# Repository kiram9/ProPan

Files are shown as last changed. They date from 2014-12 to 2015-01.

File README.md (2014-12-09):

ProPan
======
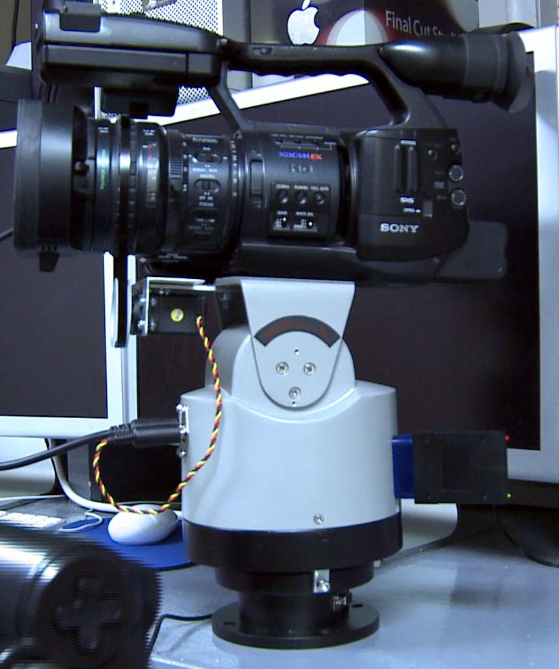
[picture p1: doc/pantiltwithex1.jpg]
ProPantilt Controller


Pan tilt control software and hardware documentation. 

Used to control a stepper based pan tilt head with a mounted sony EX-1 camera with zoom, pan, tilt, focus, and record controls. 

Compile src with arduino IDE, upload to ATMEGA 168 on board, and enjoy!

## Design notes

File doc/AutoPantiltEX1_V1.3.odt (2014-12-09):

# Auto Pan-Tilt V1.0 EX1

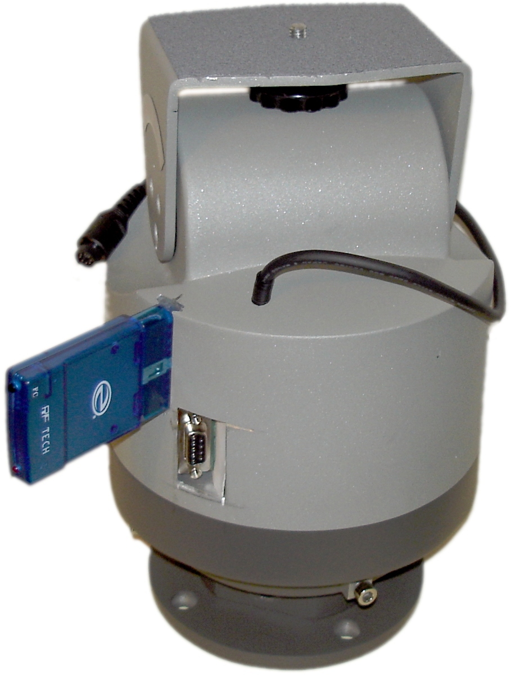
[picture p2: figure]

### Features:

- 24VDC operation
- Wireless range up to 100' (LOS)
- High accuracy
- Pan Angle: 350°
- Pan step size: 0.03°
- Tilt Angle: +/-50°
- Tilt step size: 0.01°
- Pan Speed: 0.04 to 6°/sec
- Tilt Speed: 0.02 to 3°/sec
- Ergonomic hand held controller
- Serial port control
- Open source Firmware
- Full Zoom, Focus, Record, shot review for the Sony EX-1 HD camcorder.
- Fully proportional controls
- Maximum load 6kg
- Weight 6.2kg

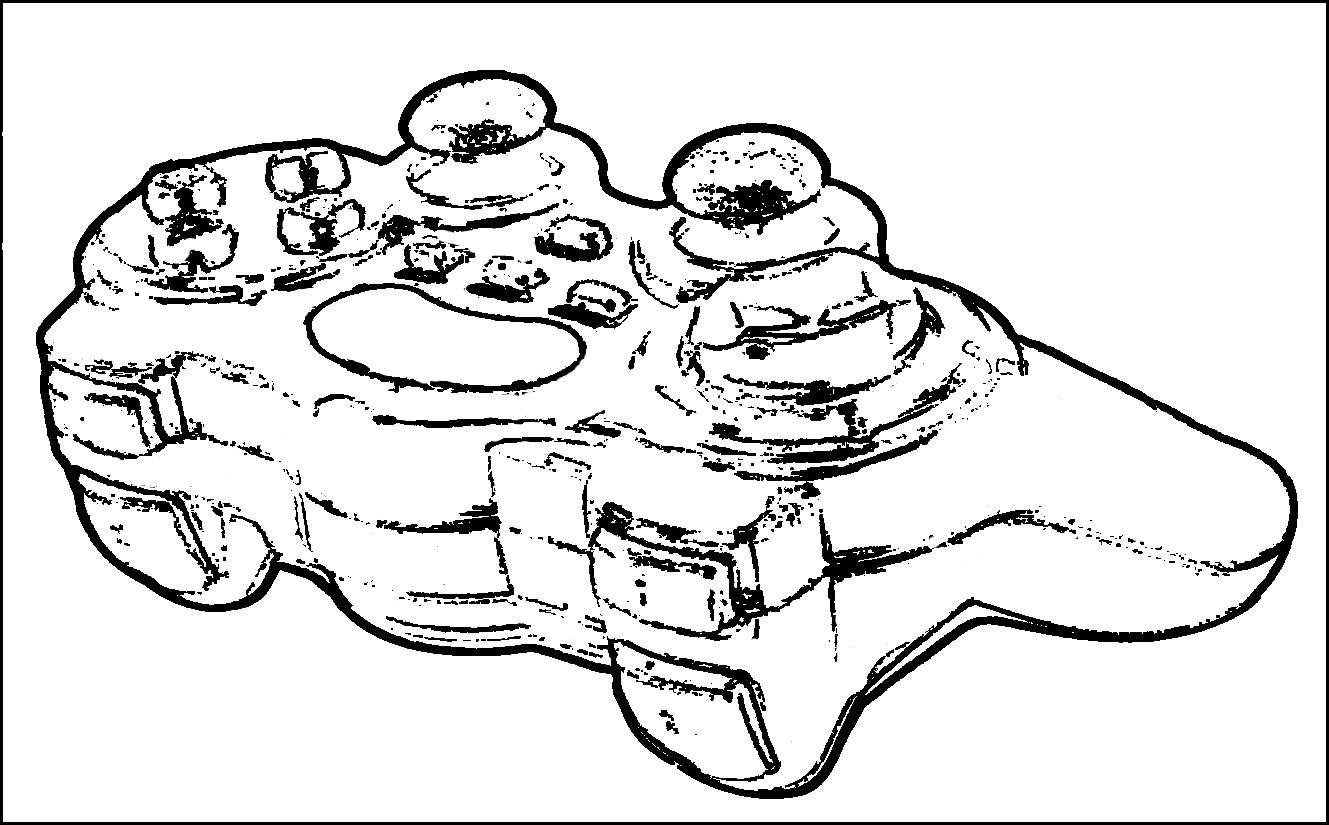
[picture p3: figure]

# Overview

The auto pan tilt with camera control wireless pan tilt head is designed for advanced motion control for the next generation of HD cameras. Incorporating 2.4GHZ hand held wireless controls, the common 24VDC power and a serial port allow this head to incorporate into almost any solution to provide high accuracy camera control at unparalleled cost. Designed for demanding environments where high precision and accuracy are a must. It also can also be used for remote sensor platform control, robotics, and range finding with its built in computer interface.

Custom configurations can be interfaced with almost any camera solution at additional cost. Other control solutions such as blue-tooth control, Zig bee based mesh networking interfaces, or integration with existing control solutions are also possible.

# Installation:

## Mounting:

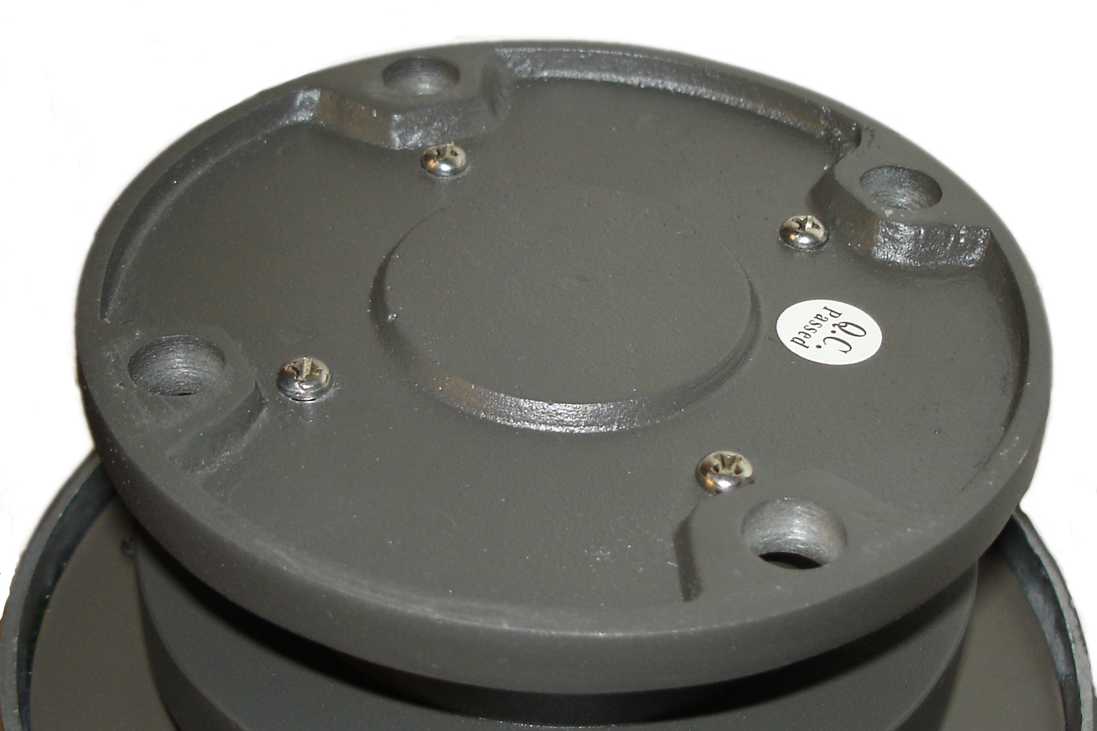
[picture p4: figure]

The Pan tilt head must be bolted using 4 bolts to a sturdy base. There is also a standard tripod mount in the middle of the base if a tripod mount is required. However for permanent operation 4 bolts to a sturdy base is preferred.

## Clearance:

Make sure that there is adequate clearance all around the camera head – whenever power is turned on the head must zero itself which means it will automatically rotate and tilt to the lower left maximum. Any equipment mounted on the head with attached cabling must have enough slack to allow this to occur otherwise damage to equipment or cabling may occur.

## Power:

The head needs 24VDC regulated power to function which is supplied through a standard center positive 2.5mm concentric barrel connector. This head should be used with the included power supply or a supply rated at least 1A at 24VDC. If using a wireless controller 4 AAA batteries are needed for the remote controller

# Controller

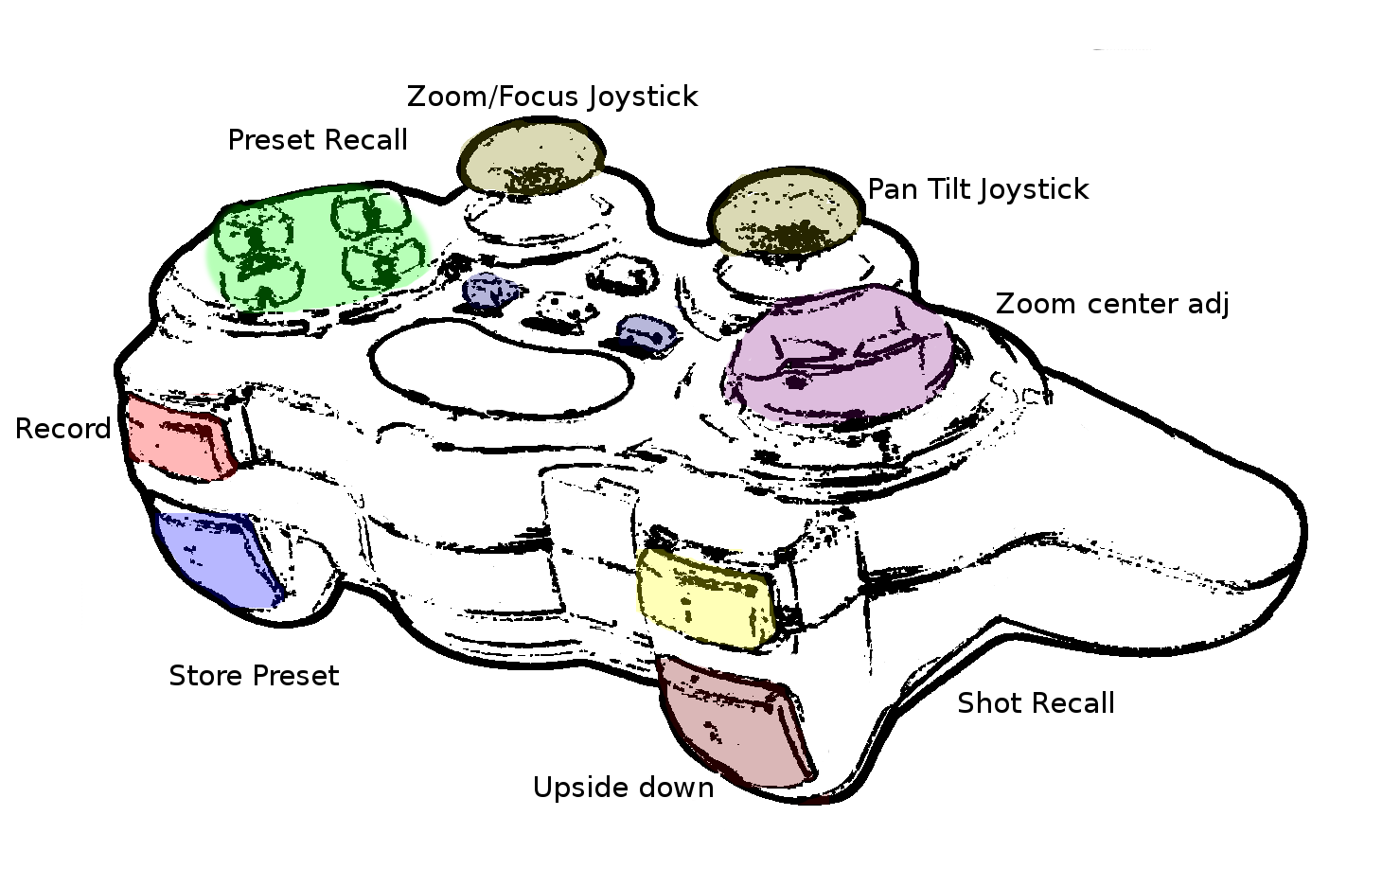
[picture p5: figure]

## Functions

### Pan and Tilt:

Using the pan tilt joystick fully proportional control of the head is assumed by the operator. A small movement of the joystick away from its center position will result in a slow pan or tilt. 8 levels of speed control are available for each direction of the pan and tilt. The Unit can be programmed to operate at very slow speeds. Using this method suitable for special filming requirements such as time-laps photography.

### Zoom and Focus

Moving the Zoom joystick forward and back will cause the zoom of the camera to zoom in and out proportionally. Currently the zoom cannot be recalled for specific presets.

### Focus (with optional accessory kit)

Moving the Zoom/Focus joystick left and right operates the focus control. This operates the special focus servo mounted under the camera allowing precision focus control.

### Record/Shot recall

The L1 and R1 buttons are used for record, and shot recall on the camera. Pressing the button will result in toggling the record/pause, and shot recall.

### Storing preset positions

To store a preset hold down the Store Preset button while selecting any one of the four preset recall buttons to overwrite the current position preset that is stored in that particular slot. These will only be stored until power loss unless the presets are stored to nonvolatile memory feature.

### Recalling preset positions

To recall a preset position press the corresponding preset recall position. If during the middle of the movement to a preset position the user requires to change the direction moving the joystick will cause the preset recall to abort and normal joystick control to resume.

## Calibration

### Setting Zoom zero point

At first use the controller will initialize to default values, this may be different from the camera's zero point. If you experience zoom creep ( a slow zooming in or out when the zoom joystick is centered) you can calibrate the zoom using the wireless controller. Hold the select button while pressing the zoom center adjust control up or down to adjust the center point. Continue this until the zoom no longer creeps in or out. This calibration will not be permanently stored through power loss until the store presets command is executed.

### Reversing the Pan tilt joystick

If reverse operation of the pan tilt joystick is required for mounting the camera backwards or upside down the joystick control can be reversed so the operator will not be confused. Hold down the select button and momentarily press the Upside down button to reverse control of the pan tilt joystick.

## Permanently storing presets, joystick settings and zoom zero point

To permanently store the zoom zero point, the pan tilt joystick reverse and all current position presets hold down the Select button and press Start. This saves all current settings into nonvolatile memory which will be saved through power loss.

# Remote Head

## Serial Port

## Power Connector

## Lens Connector

## Focus/Aux Connector

## Wireless Receiver Connector

# Physical Dimensions

# Serial Communication

## Connection information

The serial port should be connected using a straight through cable to a computer to allow serial communication. The serial port on the controller operates at 9600 baud with 8N1 format. Asserting the DTR line will cause the controller to reset.

## Boot up status information

When turning on the controller it will display via serial the firmware version as well initialization information regarding several subsystems inside the controller.

## Serial Command Structure

Serial commands are only enabled when the wireless joystick receiver is unplugged. Serial communication is entirely using human readable information. All commands will respond “OK” when received correctly.

Command | Space 0x20 | Variable 1 | Space (0X20) | Variable 2 | Linefeed 0x10
Move to pos | Space (0X20) | X position (0 to 11000) | Space (0X20) | Y position (0 to 9000) | Linefeed 0x10
M | Space (0X20) | 100 | Space (0X20) | 6438 | Linefeed 0x10
Set velocity | Space (0X20) | 1 or -1 are fastest | Linefeed 0x10
X | Space (0X20) | 1 | Linefeed 0x10
Y | Space (0X20) | -4 | Linefeed 0x10
Return current position | Returns coordinates in the form “X Y”
C | Linefeed 0x10
Run pan tilt head (enables pan – tilt unit)
G | Linefeed 0x10
Stop pan tilt head (Disables pan – tilt unit)
S | Linefeed 0x10
Toggle camera record
R | Linefeed 0x10
Set Zoom (relative speed, 0 to 255) values around 127 are approximately center
Z | Space (0X20) | 128 | Linefeed 0x10
Set Focus (relative focus, Number from 500 to 1500)
F | Space (0X20) | 900 | Linefeed 0x10

# Software Licensing

## Modifications

Modifications to the provided software or the use of other software with this unit which causes destruction or damage to the unit is will void all existing warranties. Any modifications to the unit (including software modifications are done entirely at the users risk, the manufacture provides no warranty, expressly or implied.

## GPL license

The firmware on this device is Licensed under GPL V3 by Kieran Levin. All source code is available for download at www.kieranlevin.com in compliance with the following license.

Copyright (C)2009 Kieran Levin

This program is free software: you can redistribute it and/or modify

it under the terms of the GNU General Public License as published by

the Free Software Foundation, either version 3 of the License, or

(at your option) any later version.

This program is distributed in the hope that it will be useful,

but WITHOUT ANY WARRANTY; without even the implied warranty of

MERCHANTABILITY or FITNESS FOR A PARTICULAR PURPOSE. See the

GNU General Public License for more details.

You should have received a copy of the GNU General Public License

along with this program. If not, see <http://www.gnu.org/licenses/>.

9 ©2009 Kieran Levin kieranlevin@kieranlevin.com

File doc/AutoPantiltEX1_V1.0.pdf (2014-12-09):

# Auto Pan-Tilt V1.0 EX1

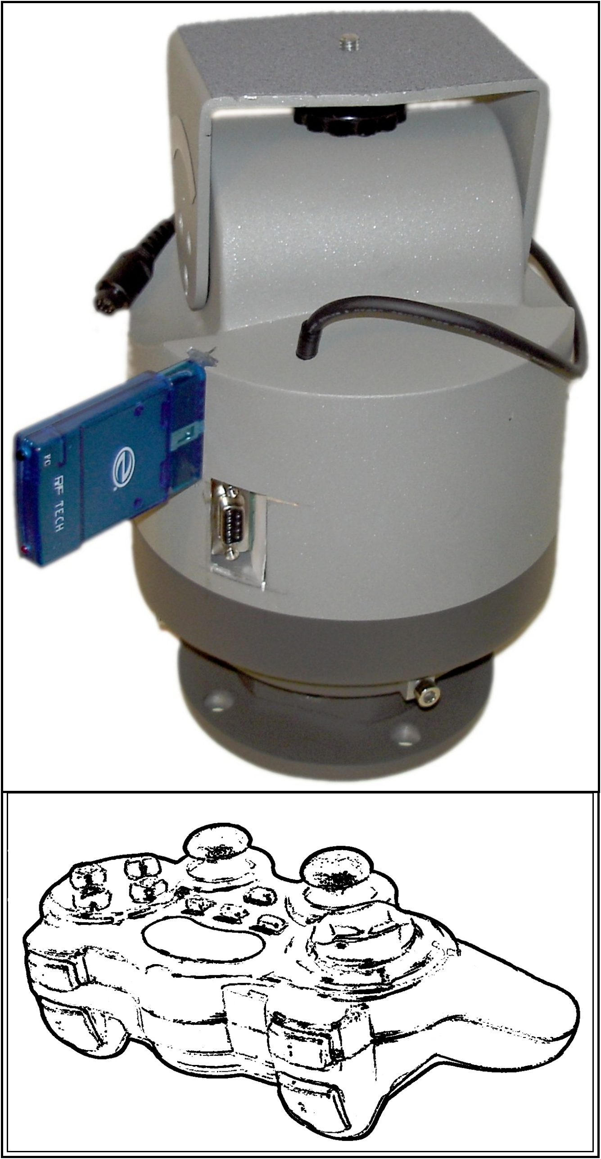
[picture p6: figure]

Features:
- 24VDC operation
- Wireless range up to 100'
- High accuracy
- Pan Angle: 350°
- Pan step size: 0.03°
- Tilt Angle: +/-50°
- Tilt step size: 0.01°
- Pan Speed: 0.04 to 6°/sec
- Tilt Speed: 0.02 to 3°/sec
- Ergonomic hand held controller
- Serial port control
- Open source Firmware
- Full Zoom, Record, shot review for the Sony EX-1 HD camcorder.
- Fully proportional controls
- Maximum load 6kg
- Weight 6.2kg
1 | ©2009 Kieran Levin kieranlevin@kieranlevin.com

## Table of Contents

## Overview

The auto pan tilt with camera control wireless pan tilt head is designed for advanced motion control for the next generation of HD cameras. Incorporating 2.4GHZ hand held wireless controls, the common 24VDC power and a serial port allow this head to incorporate into almost any solution to provide high accuracy camera control at unparalleled cost. Designed for demanding environments where high precision and accuracy are a must. It also can also be used for remote sensor platform control, robotics, and range finding with its built in computer interface.
Custom configurations can be interfaced with almost any camera solution at additional cost. Other control solutions such as blue-tooth control, Zig bee based mesh networking interfaces, or integration with existing control solutions is also possible.

## Installation:

Mounting:
The Pan tilt head must be bolted using 4 bolts to a sturdy base. This will not accept common bases such as camera tripods without a custom adapter.

Clearance:
Make sure that there is adequate clearance all around the camera head –

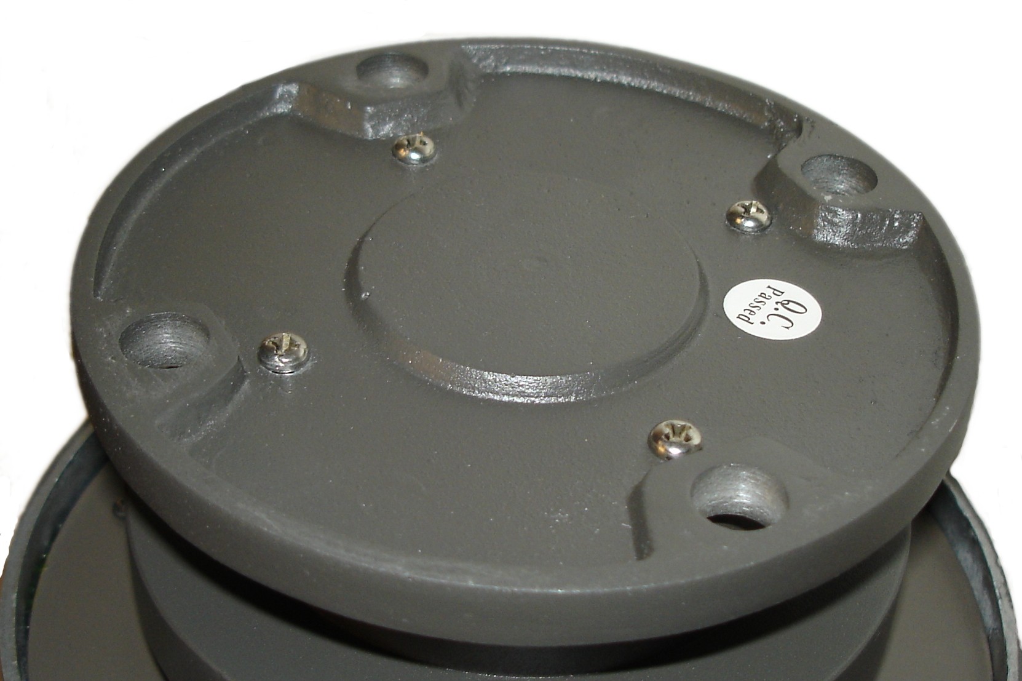
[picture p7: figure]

whenever power is turned on the head must zero itself which means it will automatically rotate and tilt to the lower left maximum. Any equipment mounted on the head with attached cabling must have enough slack to allow this to occur otherwise damage to equipment may occur.

Power:
The head needs 24VDC regulated power to function which is supplied through a standard center positive 2.5mm concentric barrel connector. This head should be used with the included power supply or a supply rated at least 1A at 24VDC. If using a wireless controller 4 AAA batteries are needed for the remote controller

## Controller

Functions

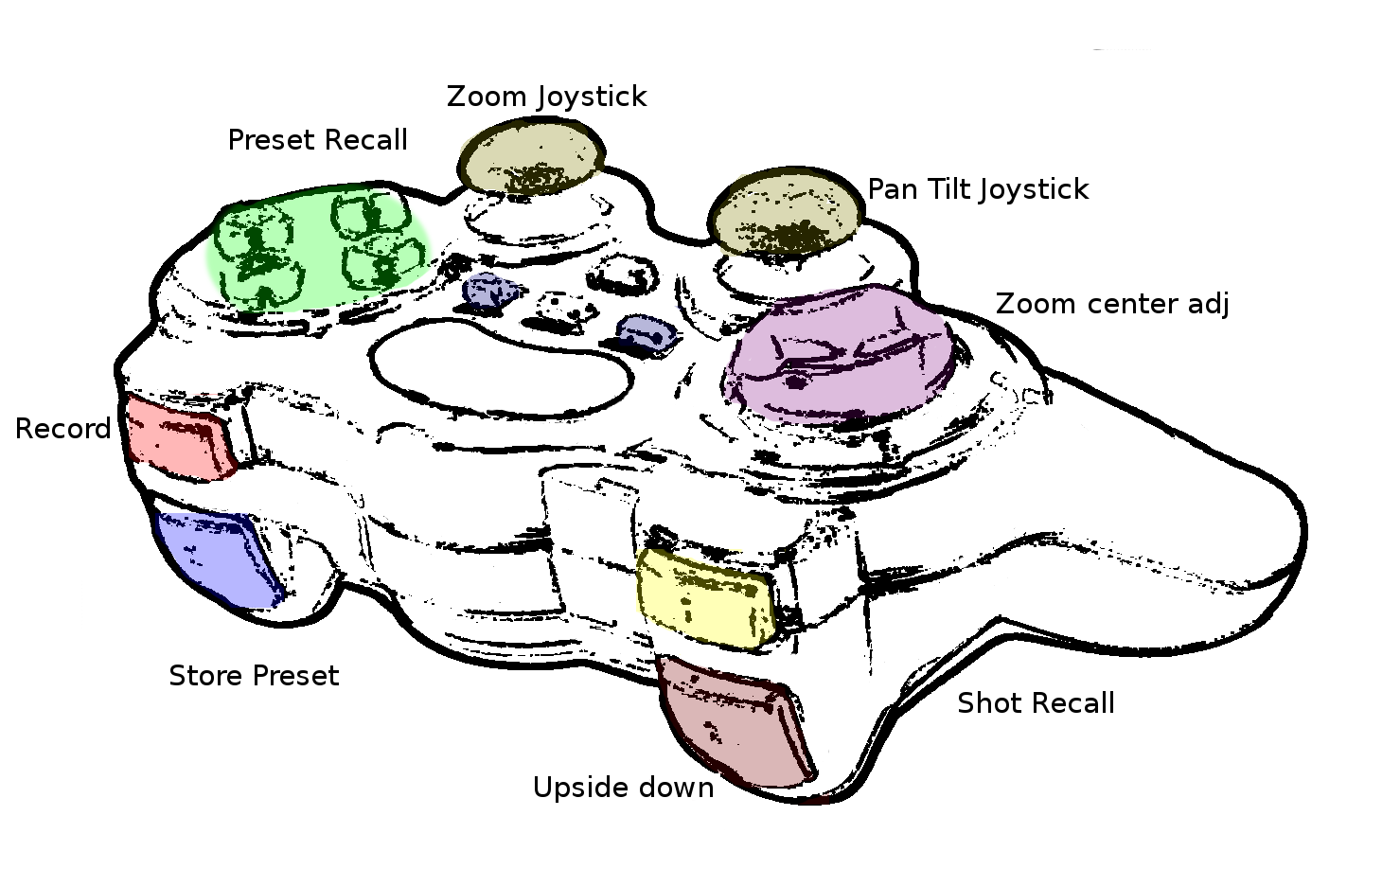
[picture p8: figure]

Pan and Tilt:
Using the pan tilt joystick fully proportional control of the head is assumed by the operator. A small movement of the joystick away from its center position will result in a slow pan or tilt. 8 levels of speed control are avaliable for each direction of the pan and tilt.

Zoom
Moving the Zoom joystick forward and back will cause the zoom of the camera to zoom in and out proportionally. Currently the zoom cannot be recalled for specific presets.

Record/Shot recall
The L1 and R1 buttons are used for record, and shot recall on the camera. Pressing the button will result in toggling the record/pause, and shot recall.

Storing preset positions
To store a preset hold down the Store Preset button while selecting any one of the four preset recall buttons to overwrite the current position preset that is stored in that particular slot. These will only be stored until power loss unless the presets are stored to nonvolatile memory feature.

Recalling preset positions
To recall a preset position press the corresponding preset recall position. If during the middle of the movement to a preset position the user requires to change the direction moving the joystick will cause the preset recall to abort and normal joystick control to resume.

## Calibration

Setting Zoom zero point
At first use the controller will initialize to default values, this may be different from the camera's zero point. If you experience zoom creep ( a slow zooming in or out when the zoom joystick is centered) you can calibrate the zoom using the wireless controller. Hold the select button while pressing the zoom center adjust control up or down to adjust the center point continue this until the zoom no longer creeps in or out. This calibration will not be permanently stored until the store presets command is executed.

Reversing the Pan tilt joystick
If reverse operation of the pan tilt joystick is required for mounting the camera backwards or upside down the joystick control can be reversed so the operator will not be confused. Hold down the select button and momentarily press the Upside down button to reverse control of the pan tilt joystick.

Permanently storing presets, joystick settings and zoom zero point
To permanently store the zoom zero point, the pan tilt joystick reverse and all current position presets hold down the Select button and press Start. The status LED on the controller will briefly go off to confirm that all current settings have been saved to nonvolatile memory.

## Serial Communication

Connection information
The serial port should be connected using a straight through cable to a computer to allow serial communication. The serial port on the controller operates at 9600 baud with 8N1 format. Asserting the DTR line will cause the controller to reset.

Boot up status information
When turning on the controller it will display via serial the firmware version as well initialization information regarding several subsystems inside the controller.

Serial Command Structure
Serial commands are only enabled when the wireless joystick receiver is unplugged. Serial communication is entirely using human readable information. All commands will respond “OK” when received correctly.
Command | Space 0x20 | Variable 1 | Space (0X20) | Variable 2 | Linefeed 0x10
Move to pos | Space (0X20) | X position (0 to 11000) | Space (0X20) | Y position (0 to 9000) | Linefeed 0x10
M | Space (0X20) | 100 | Space (0X20) | 6438 | Linefeed 0x10
Set velocity | Space (0X20) | 1 or -1 are fastest | Linefeed 0x10
X | Space (0X20) | 1 | Linefeed 0x10
Y | Space (0X20) | -4 | Linefeed 0x10
Return current position | Returns coordinates in the form “X Y”
C | Linefeed 0x10
Run pan tilt head (enables pan – tilt unit)
G

Linefeed
0x10
Stop pan tilt head (Disables pan – tilt unit) S

Linefeed
0x10
Toggle camera record
R

Linefeed
0x10
Set Zoom (relative speed, 0 to 255) values around 127 are approximately center Z

Space

(0X20) | 128 | Linefeed 0x10

## Software Licensing

Modifications
Modifications to the provided software or the use of other software with this unit which causes destruction or damage to the unit is will void all existing warranties. Any modifications to the unit (including software modifications are done entirely at the users risk, the manufacture provides no warranty, expressly or implied.

GPL license
The firmware on this device is Licensed under GPL V3 by Kieran Levin. All source code is available for download at www.kieranlevin.com in compliance with the following license.
Copyright (C)2009 Kieran Levin

This program is free software: you can redistribute it and/or modify
it under the terms of the GNU General Public License as published by the Free Software Foundation, either version 3 of the License, or
(at your option) any later version.

This program is distributed in the hope that it will be useful,
but WITHOUT ANY WARRANTY; without even the implied warranty of MERCHANTABILITY or FITNESS FOR A PARTICULAR PURPOSE. See the GNU General Public License for more details.

You should have received a copy of the GNU General Public License
along with this program. If not, see <http://www.gnu.org/licenses/>.

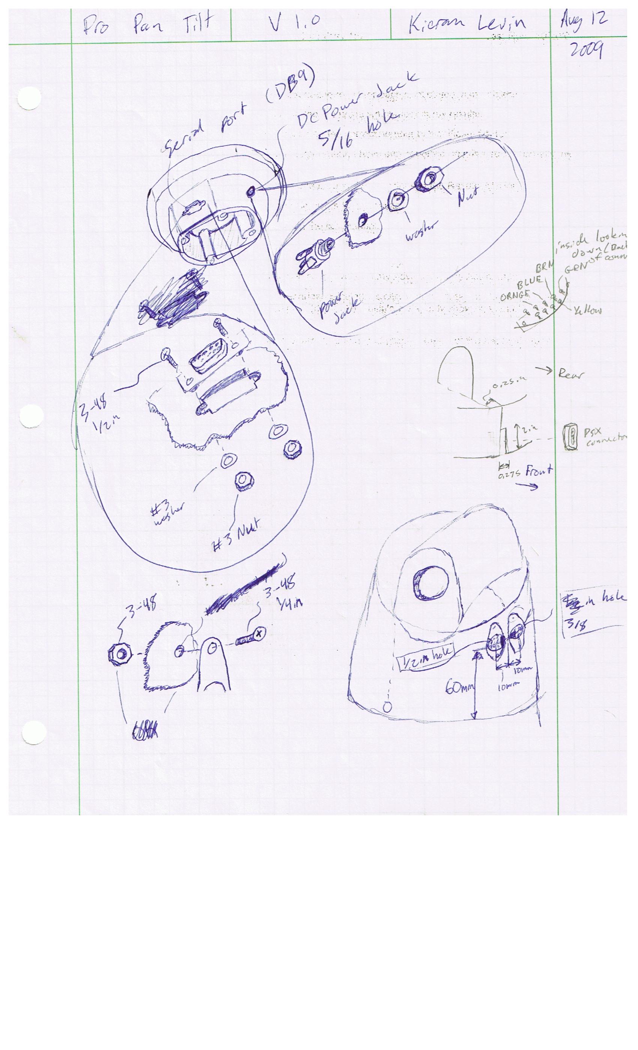
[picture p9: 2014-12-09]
doc/propantilt 001.jpg

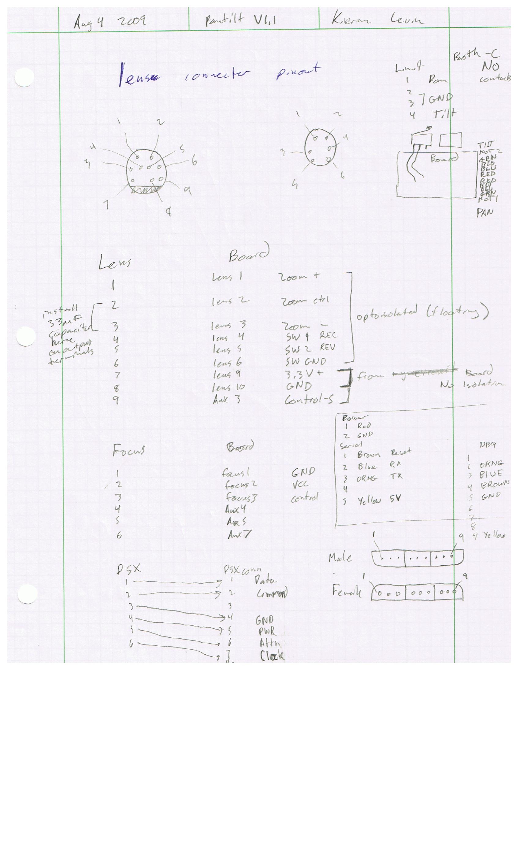
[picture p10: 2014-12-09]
doc/propantilt 002.jpg

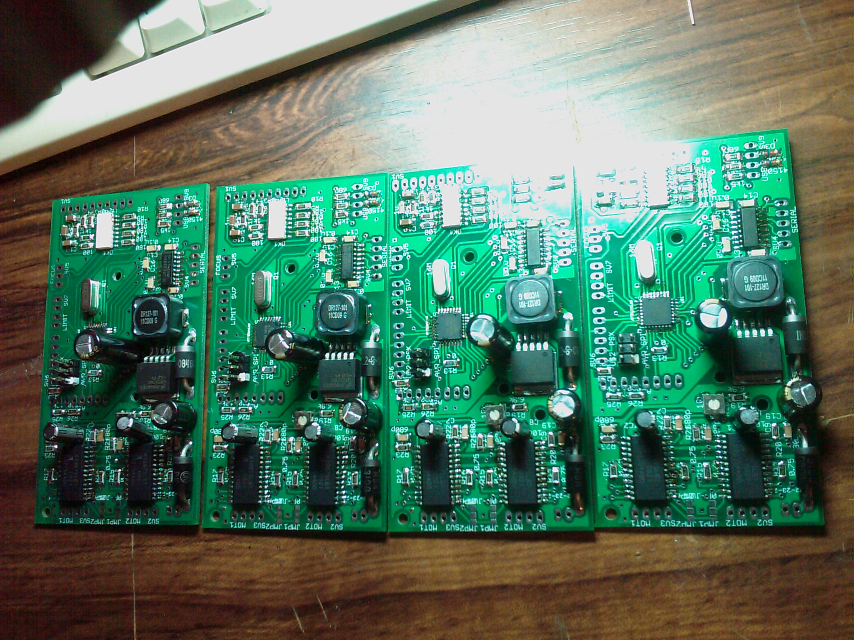
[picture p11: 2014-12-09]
doc/IMAG0068.jpg

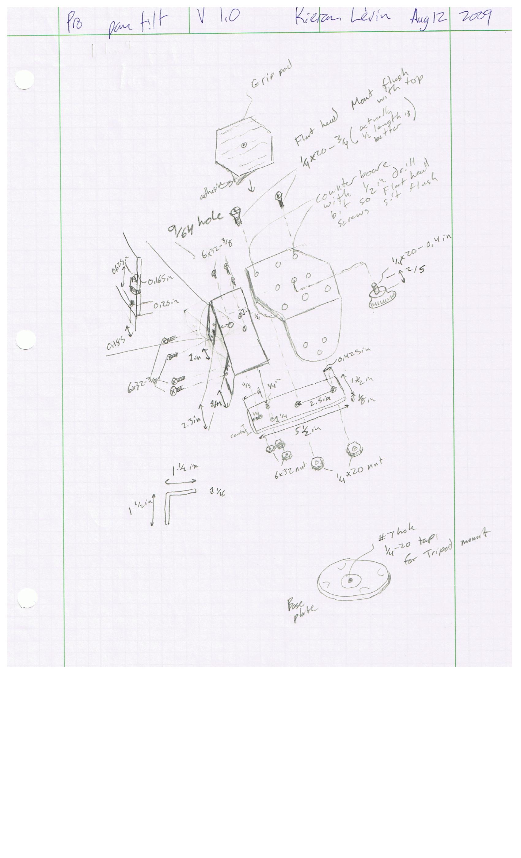
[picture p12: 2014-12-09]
doc/propantilt 003.jpg

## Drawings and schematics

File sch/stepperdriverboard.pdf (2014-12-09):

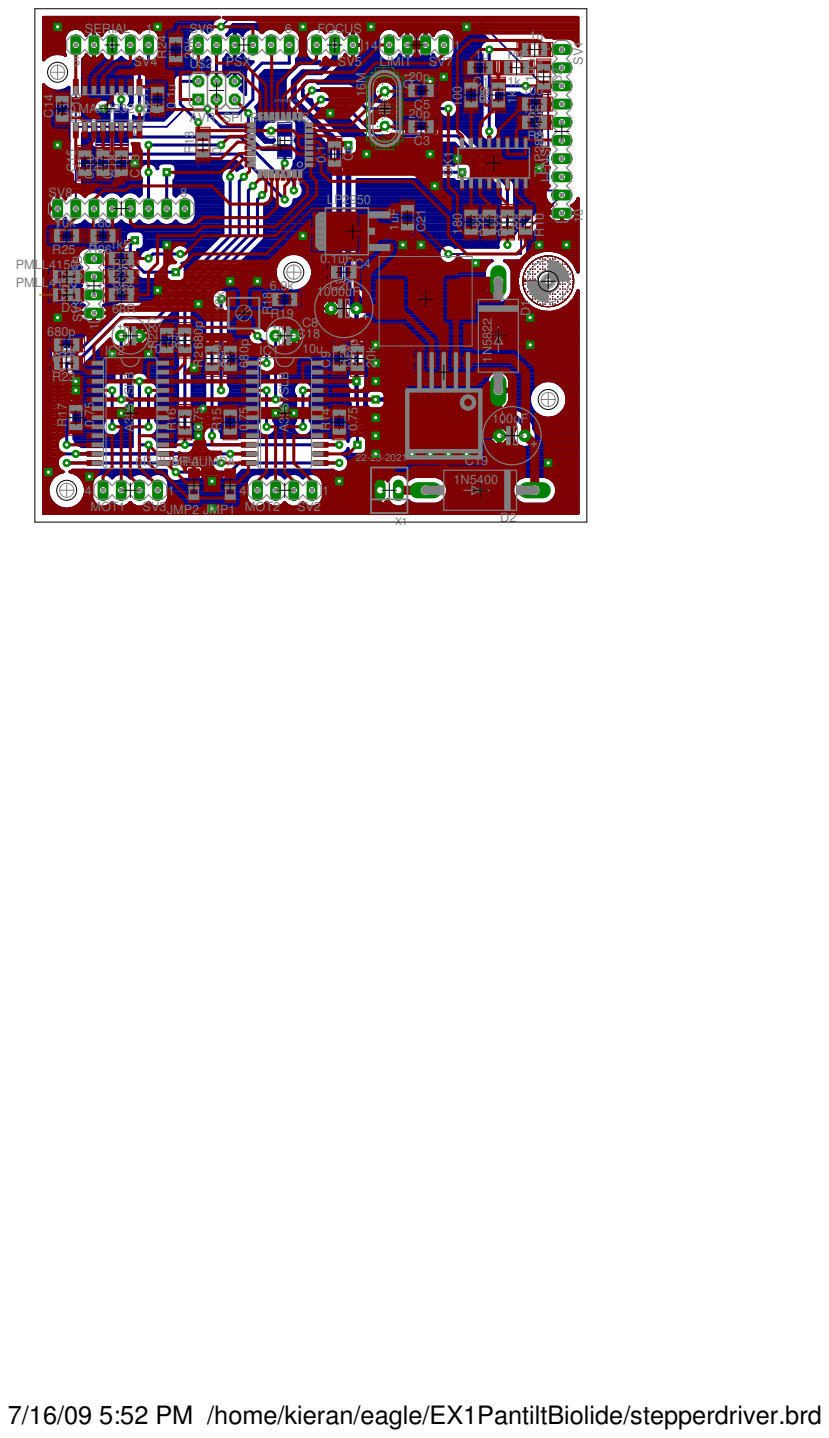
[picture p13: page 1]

7/16/09 5:52 PM /home/kieran/eagle/EX1PantiltBiolide/stepperdriver.brd

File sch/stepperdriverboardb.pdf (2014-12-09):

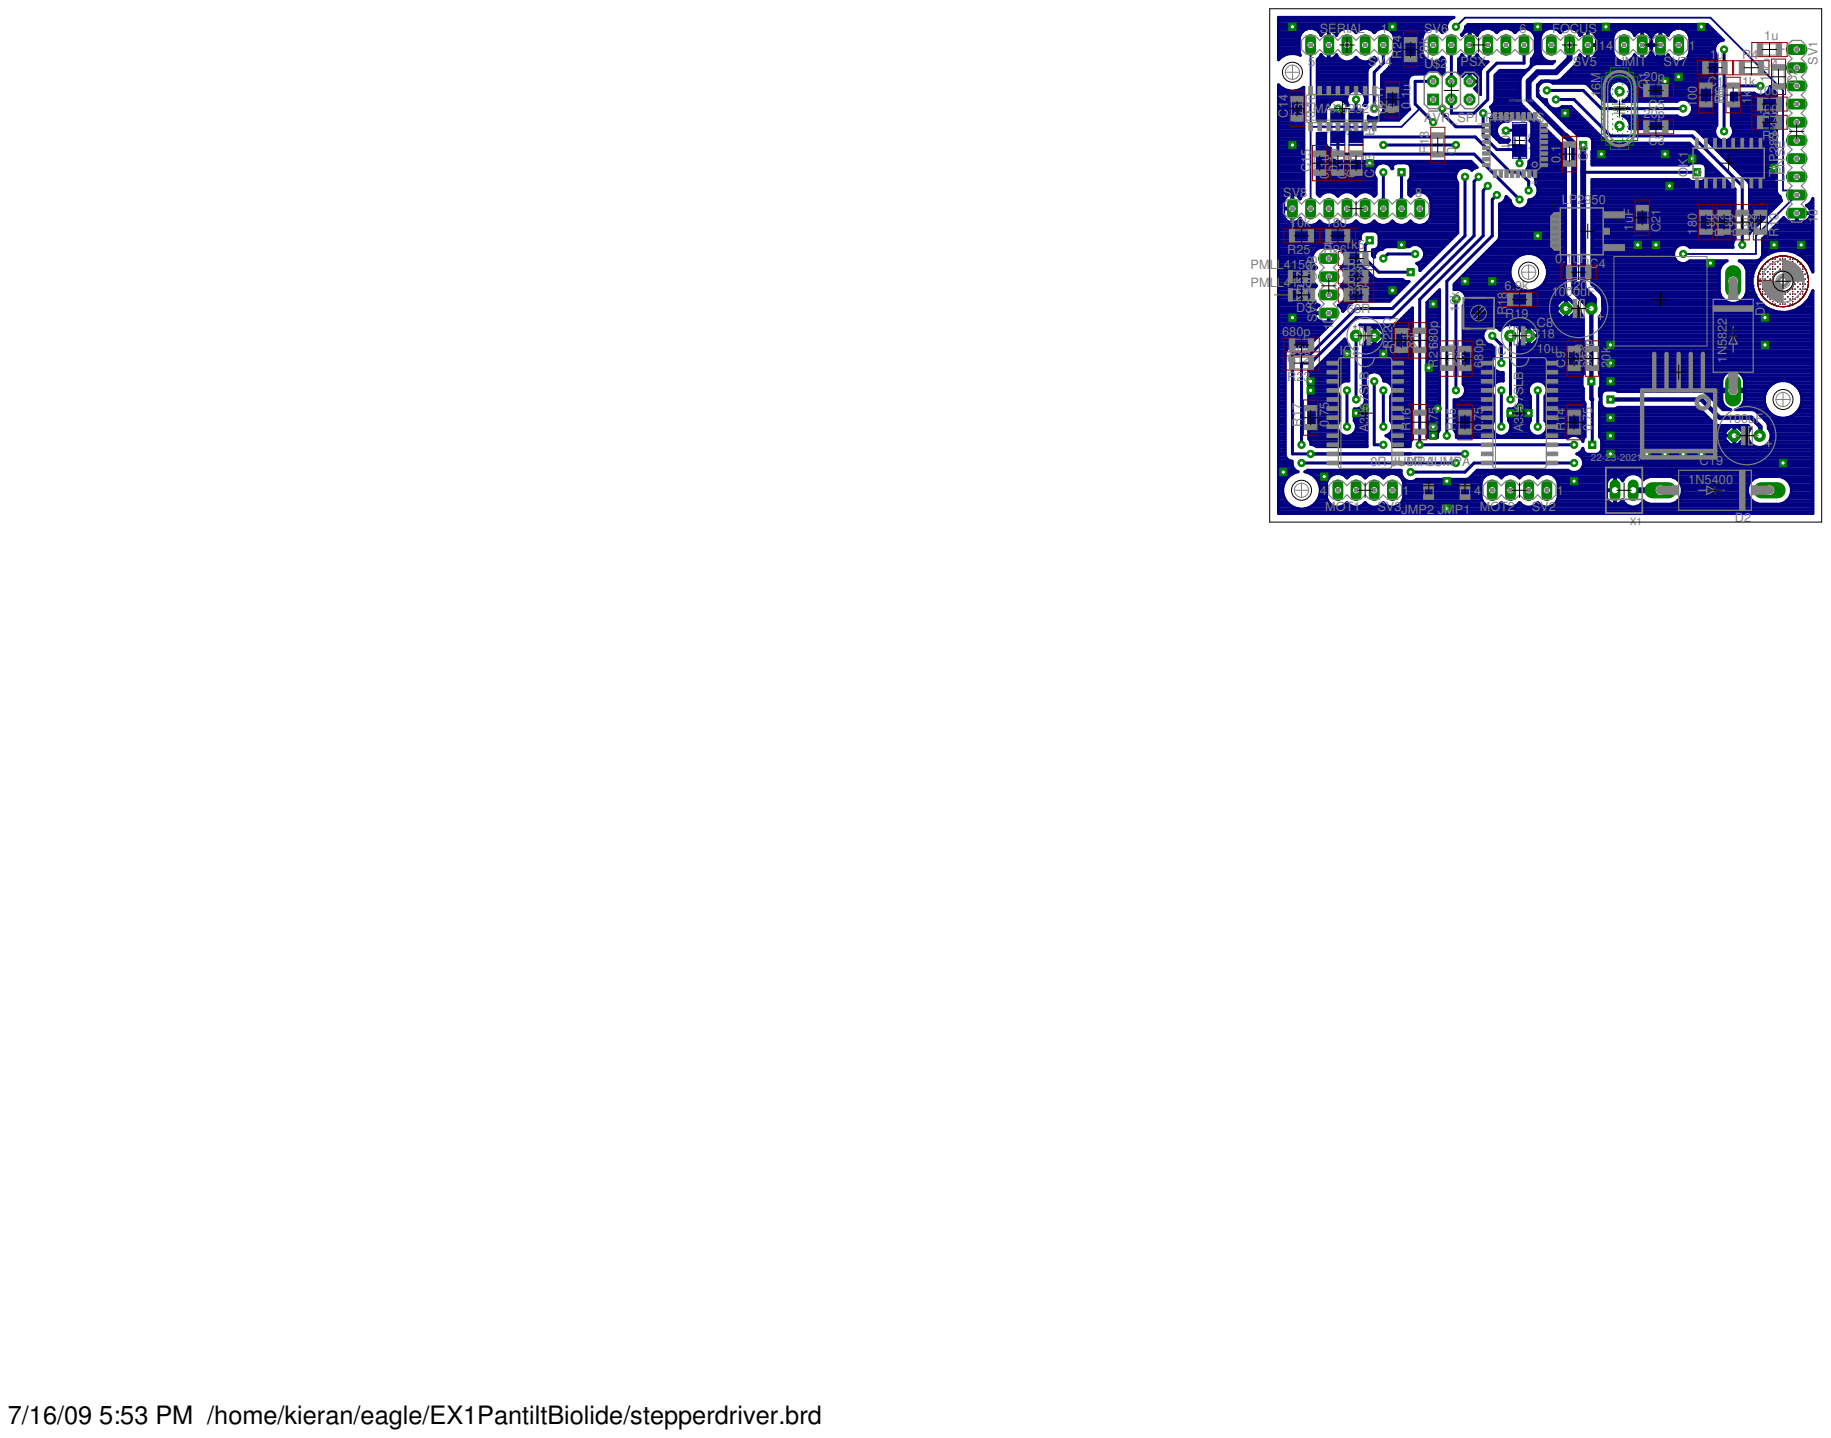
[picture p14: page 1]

0R-JUM0RP-AJUMPA | 22-23-2021

7/16/09 5:53 PM /home/kieran/eagle/EX1PantiltBiolide/stepperdriver.brd

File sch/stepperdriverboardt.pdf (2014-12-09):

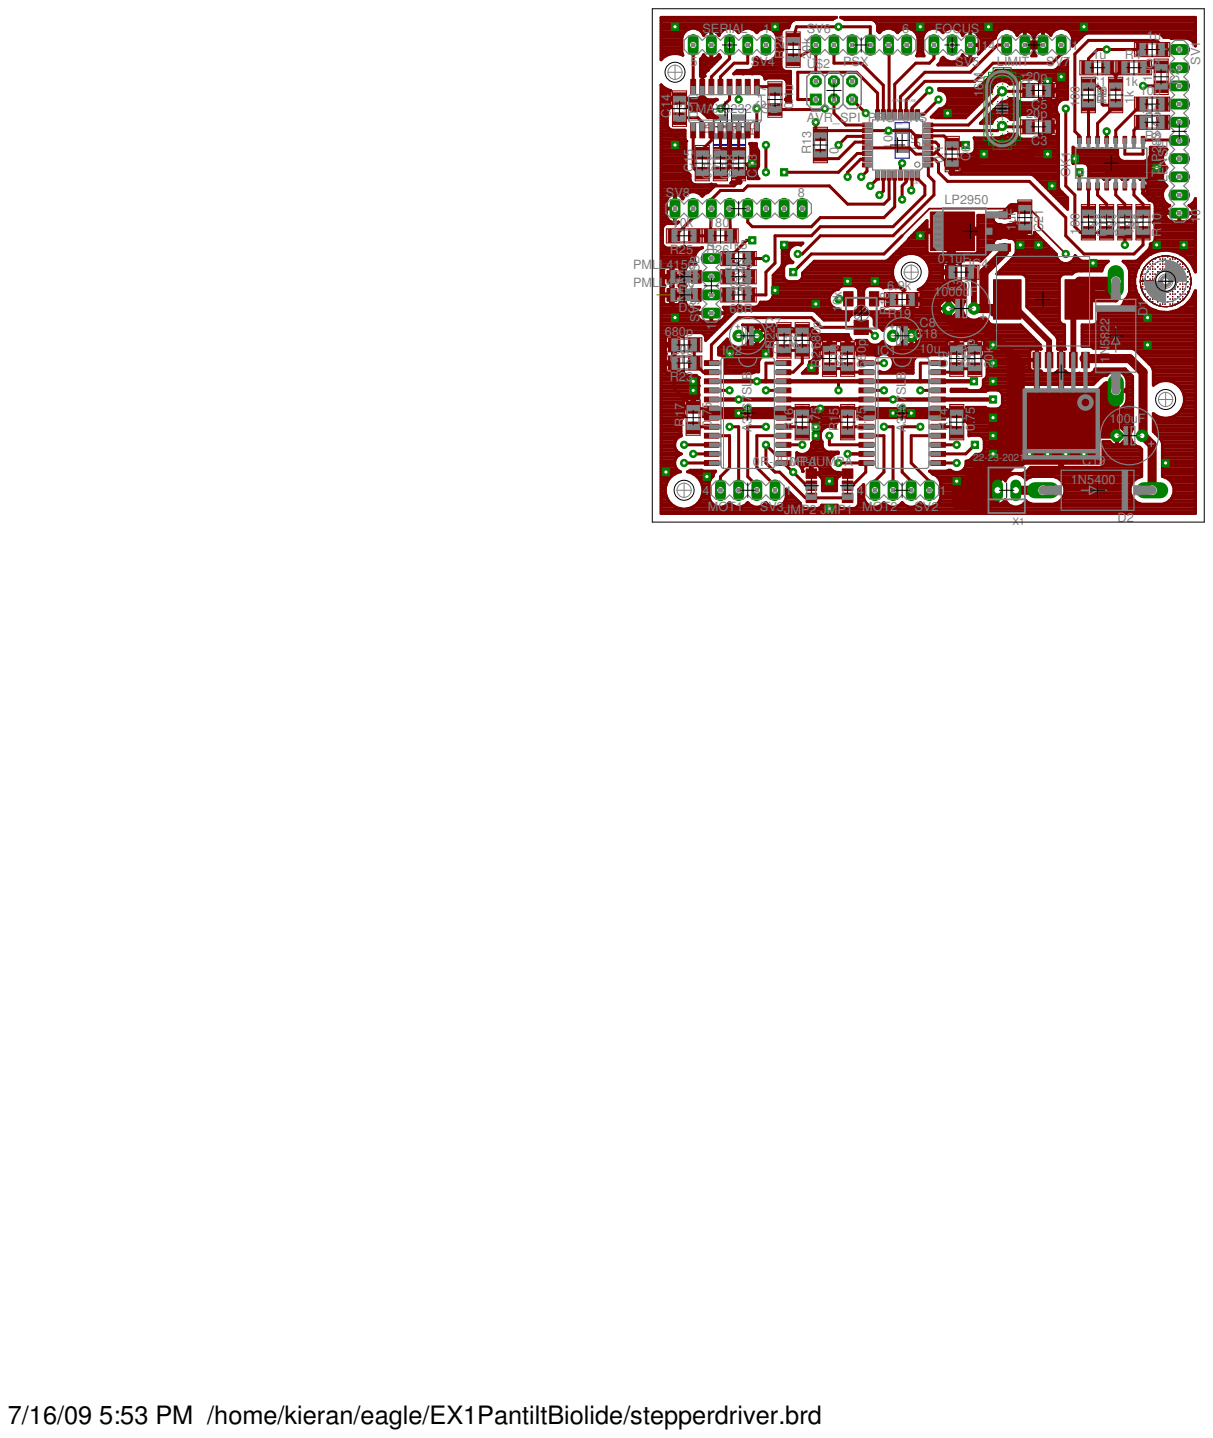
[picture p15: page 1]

SERIAL | FOCUS

7/16/09 5:53 PM /home/kieran/eagle/EX1PantiltBiolide/stepperdriver.brd

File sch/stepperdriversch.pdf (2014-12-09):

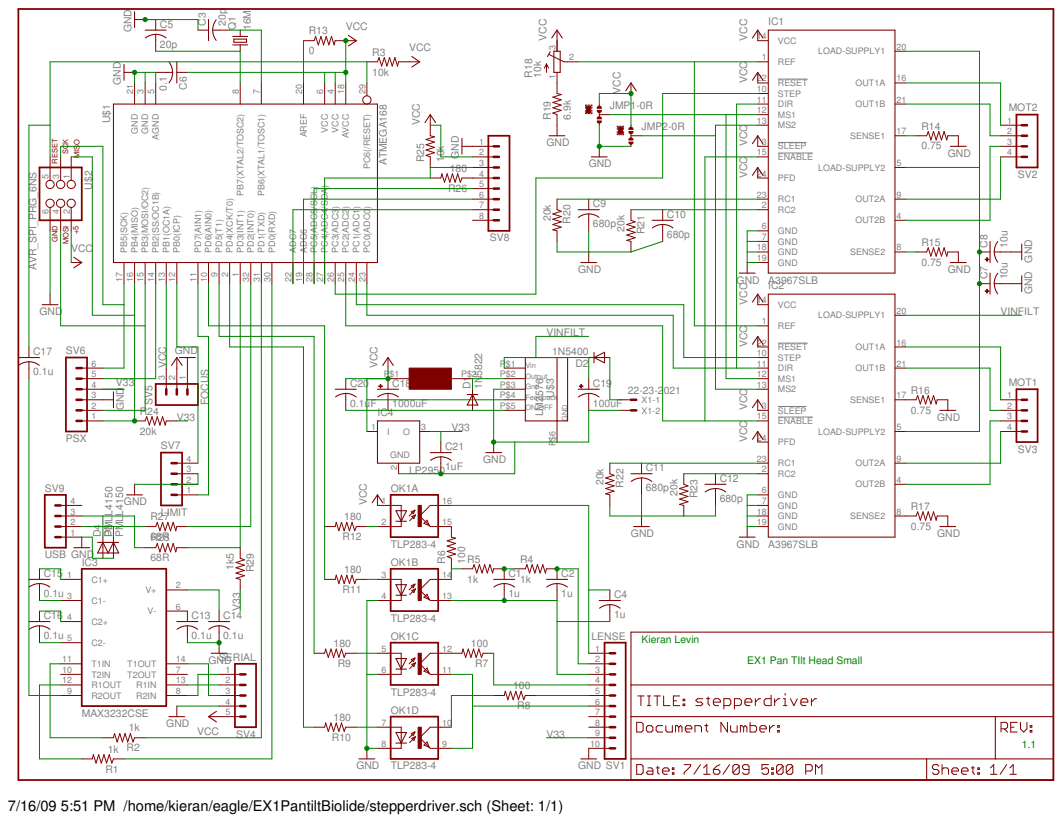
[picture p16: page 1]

VCC VCC VCC

MOSI RESET SCK MISO +5 GND

PB4(MISO) 16 PB3(MOSI/OC2) 15 PB2(SS/OC1B) 14 PB1(OC1A) 13 PB0(ICP) 12 PD7(AIN1) 11 PD6(AIN0) 10 PD5(T1) 9 PD4(XCK/T0) 2 PD3(INT1) 1 PD2(INT0) 32 PD1(TXD) 31 PD0(RXD) 30 ADC7

7/16/09 5:51 PM /home/kieran/eagle/EX1PantiltBiolide/stepperdriver.sch (Sheet: 1/1)

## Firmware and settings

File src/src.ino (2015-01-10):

/*  Pan tilt controller library (EX1Pantilt.pde)
	Written by: Kieran Levin Dec 13th, 2011
	
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
    You should have received a copy of the GNU General Public License
    along with this program.  If not, see <http://www.gnu.org/licenses/>.
*/
//TODO FIX VELOCITY RAMPING FUNCTIONS IN ATMSTEPPER.CPP 
#define VERSION  "Pan Tilt V1.3C C 2014 Kieran Levin"
#include <Spi.h>
#include <Psx_analog.h>                                          // Includes the Psx Library 

#include <ATmStepper.h>

#include <EEPROM.h>

#include <Messenger.h>

//#include <Servo.h>
#include <ServoTimeTimer1.h>
////////////////////////////////////
//Motor Definition 
//was 5
 #define StepFreqMax 5
//#define StepFreqMax 3

#define PinTiltLim 8
#define PinPanLim 7

#define PinMotorEnable 16
#define PinMotorDir 14
#define PinMotorPanStep 15
#define PinMotorTiltStep 17


/////////////////////////////////////
//Messenger definition 
Messenger message = Messenger(); 

////////////////////////////////////
//Servo definition 
#define PinServo 9
//Servo servFocus;
ServoTimeTimer1 servFocus;
uint16_t serv_cal;
///////////////////////////////////
//Controller pins definition 
#define PinData 12
#define PinCmnd 11
#define PinAtt 10
#define PinClock 13

Psx Psx;                                                  // Initializes the playstation library 
////////////////////////////////////
//Camera pins definition 
#define PinZoom  6 
#define PinRec 5
#define PinMode 4

#define CENTER  0x80
//nomalized x^3 curve to allow finer resolution control for lower values....
/*
unsigned char modifier[128] = 
{
0,0,0,0,0,0,0,0,0,0,0,0,0,0,0,0,0,0,0,0,0,1,1,1,1,1,2,2,2,3,3,3,4,4,4,5,5,6,
6,7,7,8,9,9,10,11,12,12,13,14,15,16,17,18,19,20,21,23,24,25,26,28,29,31,32,34,
35,37,39,40,42,44,46,48,50,52,54,56,59,61,63,66,68,71,73,76,79,81,84,87,90,93,
96,100,103,106,110,113,117,120,124,128,132,136,140,144,148,152,156,161,165,170,
174,179,184,189,194,199,204,209,215,220,226,231,237,243,249,255};
*/
//offset value for the zoom centering algorithm 
int offset;
//general forloop counter 
int i;

char pressed; 
char mdebug; 

// bool to keep track if the ptz controls are flipped 
char flipped; 
// hold the preset positions 
unsigned int presets[4][2]; 
#define EEPROMVALID 0
#define EEPROMVALIDVAL 0xB0
#define EEPROMCENTER 1
#define EEPROMFLIP  2
#define EEPROMSERCAL 4
#define EEPROMMEMSTART 6
// converts the raw psx output (0 to 255) to my velocity commands 1 being the fastest
int psxtovelocity(byte raw)
{
   if (raw > 230)   return (1);
   if (raw > 204)   return (2);
   if (raw > 194)   return (3);
   if (raw > 184)   return (4);
   if (raw > 174)   return (5);
   if (raw > 164)   return (6);
   if (raw > 154)   return (7);     
   if (raw > 144)   return (8);
   if (raw > 112)   return (0);
   if (raw > 102)   return (-8);     
   if (raw > 92)    return (-7);
   if (raw > 82)    return (-6);
   if (raw > 72)    return (-5);
   if (raw > 62)    return (-4);
   if (raw > 52)    return (-3);
   if (raw > 25)    return (-2);

                    return (-1);   
     
}
// handles the zoom and zoom center offset 
byte zoommodifier(byte raw)
{
  int temp;

  temp = (offset + int(raw));   // reverse the direction 
  //bounds check.... 
  if(temp < 0) temp = 0; 
  if (temp > 255) temp = 255; 
 return byte(temp);   
}
// save all NVRAM data 
void savePresets()
{  
  noInterrupts();
                  EEPROM.write(EEPROMCENTER,byte(offset));
                  EEPROM.write(EEPROMFLIP,flipped); 
                  EEPROM.write(EEPROMSERCAL, serv_cal & 0x00FF);
                  EEPROM.write(EEPROMSERCAL+1, serv_cal >> 8);
                  for(i = 0; i < 4; i++)
                  {
                     EEPROM.write(EEPROMMEMSTART + 0 + (i << 2),byte(presets[i][0] & 0xFF));
                     EEPROM.write(EEPROMMEMSTART + 1 + (i << 2),byte(presets[i][0] >> 8));
                     EEPROM.write(EEPROMMEMSTART + 2 + (i << 2),byte(presets[i][1] & 0xFF));
                     EEPROM.write(EEPROMMEMSTART + 3 + (i << 2),byte(presets[i][1] >> 8));

                  }  
  interrupts();
}
//////////////////////////////////////////////////
// Updates the focus servo 
//#define POSMAX 3000
//#define POSMIN  1750
#define POSMIN  865 //not normal but for one head yes
//#define POSBACK  15
//uint16_t servPosition; 

//byte servPosFlags; 
//byte servPosCounter;
void updateFocus(byte raw)
{
  if ((raw > 148) || (raw < 108))
  servFocus.write(serv_cal + (raw >> 2)); 
  else 
  servFocus.write(serv_cal + 0x20); 
}

void printState(){
  
  Serial.print("\n");                                            // the button data
  Serial.print(Psx.Controller_mode, HEX);     // prints value as string in hexadecimal (base 16) 
  Serial.print(','); 
  Serial.print(Psx.digital_buttons, HEX);     // prints value as string in hexadecimal (base 16)  
  Serial.print(','); 
  Serial.print(Psx.Right_x, HEX);     // prints value as string in hexadecimal (base 16)    
  Serial.print(Psx.Right_y, HEX);     // prints value as string in hexadecimal (base 16)    
  Serial.print(Psx.Left_x, HEX);     // prints value as string in hexadecimal (base 16)    
  Serial.print(Psx.Left_y, HEX);     // prints value as string in hexadecimal (base 16)      
  Serial.print(','); 
  Serial.print(psxtovelocity(Psx.Left_x), DEC);
  Serial.print(',');

  Serial.print(ATmStepper::getpos1x(), DEC);
  Serial.print(','); 
  Serial.print(ATmStepper::getpos1y(), DEC);
    Serial.print(','); 
  Serial.print(serv_cal, DEC);
  
}

// prints help on the serial interface  (does not have enough program mem window to work...)
//void serialHelp()
//{
//      Serial.println(VERSION);
//      Serial.println("Help: ");   
//      Serial.println("Command Syntax = Char Value ... Value Value (Carrage return)");  
//      Serial.println("Move to position   : 'M 100 100'  ");  
//      Serial.println("Set X velocity     : 'X 1' or 'X -1'");  
//      Serial.println("Set Y velocity     : 'Y 1' or 'Y -1'");  
//      Serial.println("Return Coordinates : 'C' Returns X Y ");  
//      Serial.println("Run Pan tilt head  : 'G'");    
//      Serial.println("Stop Pan tilt head : 'S'");     
//      Serial.println("Camera Record      : 'R'");   
//      Serial.println("Zoom               : 'R Zval(0 to 255)'");
//      Serial.println("Help (this screen) : 'h or H'");         
//}
// handles all serial messages when they are ready 
void messageReady() 
{
  int temp = 0; 
  switch (message.readChar())
  {
    case 'M': //move to position
      if(message.available()) 
      ATmStepper::setpos(message.readInt(), message.readInt()); 
      break;
    case 'X': // set X velocity 
      if(message.available()) 
      ATmStepper::setvelocity1x(message.readInt());
      break; 
    case 'Y': // set Y velocity 
      if(message.available()) 
      ATmStepper::setvelocity1y(message.readInt());
      break;   
    case 'C': // get Coordinates (returns in form X Y)  
        Serial.print(ATmStepper::getpos1x(), DEC);
        Serial.print(' '); 
        Serial.print(ATmStepper::getpos1y(), DEC);
        Serial.println("  "); 
      break; 
    case 'G': // Run head 
      ATmStepper::run(); 
      break; 
    case 'S': // Stop head 
      ATmStepper::stop(); 
      break; 
    case 'R': // trigger record 
      digitalWrite(PinRec, HIGH);
      delay(10);
      digitalWrite(PinRec, LOW);
      break; 
    case 'Z': // operate zoom 
      analogWrite(PinZoom, byte(message.readInt() + offset));
      break; 
    case 'F': //operate focus 
      servFocus.write(message.readInt()); 
      break; 
    case 'h': 
    case 'H':// show help 
      Serial.println("Help: www.kieranlevin.com"); 
      break;     
    case 'u': //remote update frame
    case 'U':
  
      
      // output analog values to correct pins 
      updateFocus(message.readInt()); 
      
      temp = message.readInt(); //zoom control
      if (temp > 148 || temp < 108){
	    analogWrite(PinZoom, zoommodifier(255-temp));
      }
      else {
        analogWrite(PinZoom, zoommodifier(0x80));
      }
      
      ATmStepper::setvelocity1x(-psxtovelocity(message.readInt()));
      ATmStepper::setvelocity1y(psxtovelocity(message.readInt()));
      
      temp = message.readInt(); //button states...
      if ( (temp & 0x01) == 0x01 )
        digitalWrite(PinRec, HIGH);
      else 
        digitalWrite(PinRec, LOW);
        
      if ( (temp & 0xc) == 0x0c){
        Serial.println("Saving settings"); 
        savePresets();
        delay(1000);
      }else if ( (temp & 0xc) == 0x08){
        offset++;
        delay(250);
      }else if ( (temp & 0xc) == 0x04){
        offset--;
        delay(250);
      }
      //Serial.println("Got remote update"); 
      break; 
    case 'd':
    case 'D':
      mdebug = mdebug^1;
      break; 
      
    default: 
      Serial.println("Invalid"); 
      break; 
  }
      
       // Loop through all the available elements of the message
       while ( message.available() ) 
       {
	  // There must be some garbage at the end of the message
          message.readInt();
          Serial.println("Garbage in message Detected"); 
       }
       //Serial.println("OK"); 
}




// initialize the controller head 
void setup()
{
  //delay(10);
  Serial.begin(4800); 
  Serial.println(VERSION);
  Serial.println("Please wait..."); 
  ///////////////////////////////////////////
  Serial.println("Initializing..."); 
  Serial.println("\tHead...");
  delay(100);
  ATmStepper::ATmStepperInit(StepFreqMax,PinMotorPanStep,PinMotorTiltStep,PinMotorDir,PinMotorEnable,PinPanLim,PinTiltLim); 
  Serial.println("\tCentering Head...");
  //TmStepper::setpos(7000,5000);
  ATmStepper::setpos(70,50);
  delay(300);
  /////////////////////////////////////////////////////
  Serial.println("\tNVRAM...");   
  pressed = 0;
  mdebug = 0;
  if(EEPROMVALIDVAL == EEPROM.read(EEPROMVALID))
  { 
    offset = int(char(EEPROM.read(EEPROMCENTER)));
    flipped = EEPROM.read(EEPROMFLIP); 
    serv_cal = EEPROM.read(EEPROMSERCAL) | (EEPROM.read(EEPROMSERCAL + 1) << 8);;
    for(i = 0; i < 4; i++)
    {
       presets[i][0] = int(EEPROM.read(EEPROMMEMSTART + 0 + (i << 2))) | ( int(EEPROM.read(EEPROMMEMSTART + 1 + (i << 2))) << 8);
       presets[i][1] = int(EEPROM.read(EEPROMMEMSTART + 2 + (i << 2))) | ( int(EEPROM.read(EEPROMMEMSTART + 3 + (i << 2))) << 8);
    }
  }
  else
  {
    Serial.println("\tInvalid NVRAM...Defaults Loaded");   
    EEPROM.write(EEPROMCENTER, 0);
    EEPROM.write(EEPROMFLIP, 0); 
    EEPROM.write(EEPROMVALID, EEPROMVALIDVAL); 
    EEPROM.write(EEPROMSERCAL,byte(POSMIN  & 0x00FF));
    EEPROM.write(EEPROMSERCAL+1, byte(POSMIN >> 8));
    
    
  }
  pinMode(PinRec,OUTPUT);
  pinMode(PinMode,OUTPUT);
  pinMode(PinZoom,OUTPUT);
  digitalWrite(PinRec, LOW);
  digitalWrite(PinMode, LOW);
  analogWrite(PinZoom, byte(offset));
  ////////////////////////////////////////
  Serial.println("\tPSX...");   

  Psx.setupPins(PinData, PinCmnd, PinAtt, PinClock);  // Defines what each pin is used
                                                      // (Data Pin #, Cmnd Pin #, Att Pin #, Clk Pin #)
  delayMicroseconds(10);                                
  noInterrupts();
  Psx.initcontroller(psxAnalog);    
  interrupts();
  delayMicroseconds(10);  


  ///////////////////////////////////////////
  Serial.println("\tSerial Com..."); 
  message.attach(messageReady);
  ///////////////////////////////////////////

  servFocus.attach(9); 
  servFocus.write(serv_cal + 0x20);

  Serial.println("Initialization complete."); 

}

  

void loop()
{
  
  
  Psx.poll();					// update controller values 
  //if there is no controller connected... handle serial commands...
  if(0xFF == Psx.Controller_mode)
  {
    //handle any serial commands that may come our way...
    while ( Serial.available() )  message.process(Serial.read () );
     
  }
  // only update if the controller is connected and in the analog mode
  else if(0x70 == (Psx.Controller_mode & 0xF0))
  {
          // handle updating the controller speed from data read from position indicator...
	  if(flipped)
	  {
	    ATmStepper::setvelocity1x(-psxtovelocity(Psx.Left_x));  
	    ATmStepper::setvelocity1y(psxtovelocity(Psx.Left_y));
	  }
	  else 
	  {
	    ATmStepper::setvelocity1x(psxtovelocity(Psx.Left_x));  
	    ATmStepper::setvelocity1y(-psxtovelocity(Psx.Left_y));    
	  }

	  // output analog values to correct pins 
          if (Psx.Right_y > 148 || Psx.Right_y < 108){
	    analogWrite(PinZoom, zoommodifier(Psx.Right_y));
          }
          else {
            analogWrite(PinZoom, zoommodifier(0x80));
          }
          updateFocus(Psx.Right_x); 

	  // Handle any button press here
	  if (Psx.digital_buttons & (psxR1))
	    digitalWrite(PinRec, HIGH);
	  else
	    digitalWrite(PinRec, LOW);

	  if (Psx.digital_buttons & (psxL1))
            digitalWrite(PinMode, HIGH);
	  else
	    digitalWrite(PinMode, LOW);

          //we need to handle our interface parameter setup here....
          if(Psx.digital_buttons & psxSlct)
          {
            //update the center offset here 
            if(Psx.digital_buttons & psxUp)
            {
             offset++;
             delay(250);  
            }
            if(Psx.digital_buttons & psxDown)
            {
             offset--; 
             delay(250); 
            }
            if(Psx.digital_buttons & psxLeft)
            {
             serv_cal-=1;
             //delay(50);  
            }
            if(Psx.digital_buttons & psxRight)
            {
             serv_cal+=1; 
             //delay(50); 
            }
                        
            //Save all our current settings
            if(Psx.digital_buttons & psxStrt)
            {
              savePresets();
              noInterrupts();
              //Psx.Motorlarge = 0xFF;
              Psx.initcontroller(psxDigital);
              interrupts();
              delay(1000);
              //Psx.Motorlarge = 0x00;
            }
            // flip the joystick for backward operation 
            if(Psx.digital_buttons & psxL2)
            {
              if(flipped)
                flipped = 0;
              else flipped = 1; 
              
              delay(500);
            }
            //do a complete system restart
            if(Psx.digital_buttons & psxJoyL)
              asm volatile ("  jmp 0");

          }
            // do all our position memory settings here
          //
          switch(Psx.digital_buttons & 0xF200)
          {
            //save our preset to temp memory (hold down R2 and press any one of the following 
           case 0x8200:
             presets[0][0] = ATmStepper::getpos1x();
             presets[0][1] = ATmStepper::getpos1y();
            break; 
           case 0x4200: 
             presets[1][0] = ATmStepper::getpos1x();
             presets[1][1] = ATmStepper::getpos1y();          
            break; 
           case 0x2200: 
             presets[2][0] = ATmStepper::getpos1x();
             presets[2][1] = ATmStepper::getpos1y();           
            break;
           case 0x1200: 
             presets[3][0] = ATmStepper::getpos1x();
             presets[3][1] = ATmStepper::getpos1y();           
            break; 
            //recall preset from temp memory 
           case 0x8000: 
             ATmStepper::setpos(presets[0][0], presets[0][1]);
           break;
           case 0x4000: 
             ATmStepper::setpos(presets[1][0], presets[1][1]);
            break; 
           case 0x2000: 
             ATmStepper::setpos(presets[2][0], presets[2][1]);
            break; 
           case 0x1000: 
             ATmStepper::setpos(presets[3][0], presets[3][1]);
            break; 
           default: 
            break;
          }
  }
  else if (0x40 == (Psx.Controller_mode & 0xF0)) // then we are in digital mode... we should switch to analog
  {
    noInterrupts();
    Psx.initcontroller(psxAnalog);
    interrupts();
    delay(100);
  }
  //Debugging information.... 
  if (mdebug){
    printState();
  }
}

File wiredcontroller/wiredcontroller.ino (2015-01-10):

int buttonVal = 0; 
void setup(){
  pinMode(10, INPUT_PULLUP);
  pinMode(11, INPUT_PULLUP);
  pinMode(12, INPUT_PULLUP);
  pinMode(13, INPUT_PULLUP);
  
  
  Serial.begin(4800); 
  
  
}


void loop(){
  //read 4 analog values and switch states
  buttonVal = 0;
  Serial.print("u "); 
  Serial.print(map(analogRead(A0),0,1023,0,255)); 
  Serial.print(" "); 
  Serial.print(map(analogRead(A1),0,1023,0,255)); 
  Serial.print(" "); 
  Serial.print(map(analogRead(A2),0,1023,0,255)); 
  Serial.print(" "); 
  Serial.print(map(analogRead(A3),0,1023,0,255)); 
  Serial.print(" "); 
  buttonVal |= digitalRead(10) ? 0:1; 
  buttonVal |= digitalRead(11) ? 0:2; 
  buttonVal |= digitalRead(12) ? 0:4; 
  buttonVal |= digitalRead(13) ? 0:8; 
  Serial.print(buttonVal); 
  Serial.print("\r\n");
  delay(32);
}
